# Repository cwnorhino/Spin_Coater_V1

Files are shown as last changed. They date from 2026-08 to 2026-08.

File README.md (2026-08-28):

Spin coating is a common technique for applying thin films to substrates. When a solution of a material and a solvent is spun at high speeds using a spin coater, the centripetal force and the surface tension of the liquid together create an even covering. After any remaining solvent has evaporated, spin coating results in a thin film ranging from a few nanometres to a few microns in thickness.

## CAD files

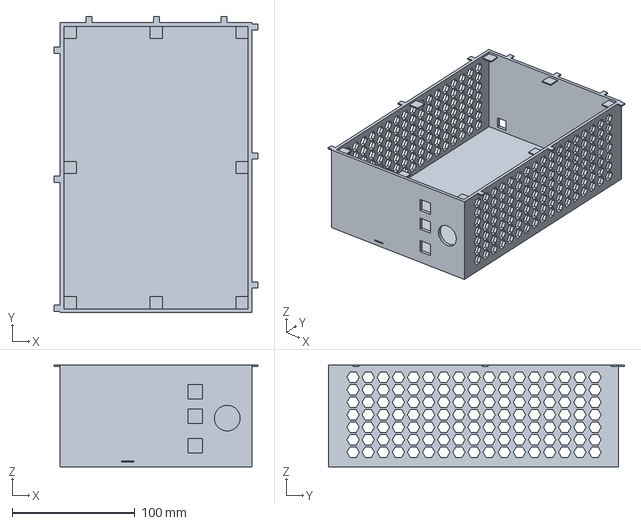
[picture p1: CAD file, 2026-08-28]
cad/spin_coater_v1.FCStd
166.0 x 241.0 x 83.0 mm

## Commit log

2026-08-28 added gitignore and schematic files
    [Circuit_v1.kicad_pcb, Circuit_v1.kicad_sch]
2026-08-28 cad file for bottom layer
    [spin_coater_v1.FCStd]
2026-08-28 bottom layer cad mostly done
    [spin_coater_v1.FCStd]
2026-08-28 changed the dimensions to fit on the printer bed
    [spin_coater_v1.FCStd]
2026-10-17 Add ESP32 spin-coater firmware (OLED UI, ramp engine, safety interlocks)
    - ESP32 DevKit + SimonK 30A ESC + A2212 motor control via servo PWM
    - SSD1306 OLED UI with 4x4 keypad: RPM, ramp-up/hold/ramp-down, ease curves
    - Safety: ESC arming, absolute RPM ceiling, current derate, overspeed/tach trips, E-stop
    - Native unit tests for ramp/safety math (6/6 passing)
    - Worded circuit build guide (CIRCUIT.md) and future TODO (WiFi AP + BLE)
2026-10-19 Firmware: fix tach RPM, fault clear, E-stop input; usable edit menu (#1)
    - Tach: period-based RPM measurement (old 100 ms count reported rev/s, 60x low,
    so the overspeed trip could never fire); noise rejection and timeout
    - Fault screen: D now actually clears a latched fault (after E-stop released
    and rotor stopped); previously required a power cycle
    - GPIO34/35 have no internal pull-ups: use INPUT, require external 10k,
    add USE_ESTOP_PIN / USE_TACHO and ESTOP_ACTIVE_LEVEL config
    - ESC: 16-bit LEDC timer (was 10-bit, ~19.5 us steps); set after attach()
    - Safety: clamp to profile cap, overspeed at cap+500, any latched fault
    outputs 0, tach-lost/stall no longer needs a prior pulse
    - UI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
2026-10-19 Add controller schematic (KiCad 10) for Spin Coater v1 (#2)
    Fills the empty Circuit_v1.kicad_sch with the full controller wiring:
    12V input with 1000uF bulk cap, 1N4007 + 12V->5V buck, SimonK 30A ESC and
    A2212 motor, ESP32 DevKit V1 (30-pin DOIT), SSD1306 OLED, 4x4 keypad,
    tachometer and E-stop with the 10k pull-ups GPIO34/35 need, and an
    optional NPN buzzer driver.
    Nets follow firmware/include/config.h and firmware/CIRCUIT.md. Custom
    symbols live in the project library spincoater.kicad_sym (sym-lib-table).
    ERC: 0 errors, 0 warnings (kicad-cli 10.0.7, all severities).
    .kicad_pro and .kicad_pcb are unchanged.
2026-10-19 docs: CIRCUIT.md steps 12/13 match PR #1 firmware (external 10k pull-ups, USE_TACHO/USE_ESTOP_PIN) + PR #2 schematic refs (R1/R2/SW1)
2026-10-20 updated cad files
2026-10-31 spec: closed-loop feedback + 60s RPM calibration design (Option A)
2026-10-31 fix: test sketches match real pins (ir->GPIO23, esc->GPIO13)
2026-10-31 fix: straight label-order keymap verified by on-device KEY TEST
2026-10-31 feat: OTA progress % + bar (throttled redraw), version 1.3.1
